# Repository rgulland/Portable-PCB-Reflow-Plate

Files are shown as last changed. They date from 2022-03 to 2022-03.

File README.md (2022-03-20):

# Portable PCB Reflow Plate
A PCB reflow plate optimized for medium size boards.  
Design, assembly & testing documentation at https://rgulland.com/blog/2022/3/11/reflow-heater

# Build Notes
Please don't build this unless you're confident working with mains power and have sufficient materials to do it safely. This build is rather fiddly and time consuming: if you're unsure I'm considering making a v2 that comes as a kit with custom electronics, contact me if you're interested in that.  
On initial power on, make sure to set a default power limit of 125-150W & 30.1V on the DSP5005 when using the AC input. Above these limits, the AC-DC converter components will have a shorter life due to high temperatures.

# LICENSE
This project is under the GPL v3 license. There's little to no IP here, as most components are COTS, so this is more an endorsement of keeping more things open source. Open source hardware projects are rare, so if yours is, thanks :)  
https://www.gnu.org/licenses/gpl-3.0.en.html

# Changes Since Blog
- Adjusted microcontroller port cutout
- Added draft to bottom cap to better tolerate 3D printed parts' first layer flange / 'elephant's foot'
- Separated code into multiple files & commented for readability

# Todo
- Improve code
  - Generally remove jank / simplify screen update system
  - Re-implement PID control
  - Add thermal runaway detection / better AC lockout
  - PID settings / tuning menu
  - Add curve edit mode
- Design / Build / Test v2 
  - SD card / spi flash / other permanent storage for reflow curves
  - Cheaper thermal insulation solution
  - Lower cost MCU (ideally w/ BLE or wifi for future expandability)
  - Wiring condensed into 3 custom PCBs to reduce assembly time
  - Smaller AC port (fused IEC 60320) & SPST switch
  - Larger cooling fan
  - Solution for cooling PCBs faster
  - SSR for finer PID control

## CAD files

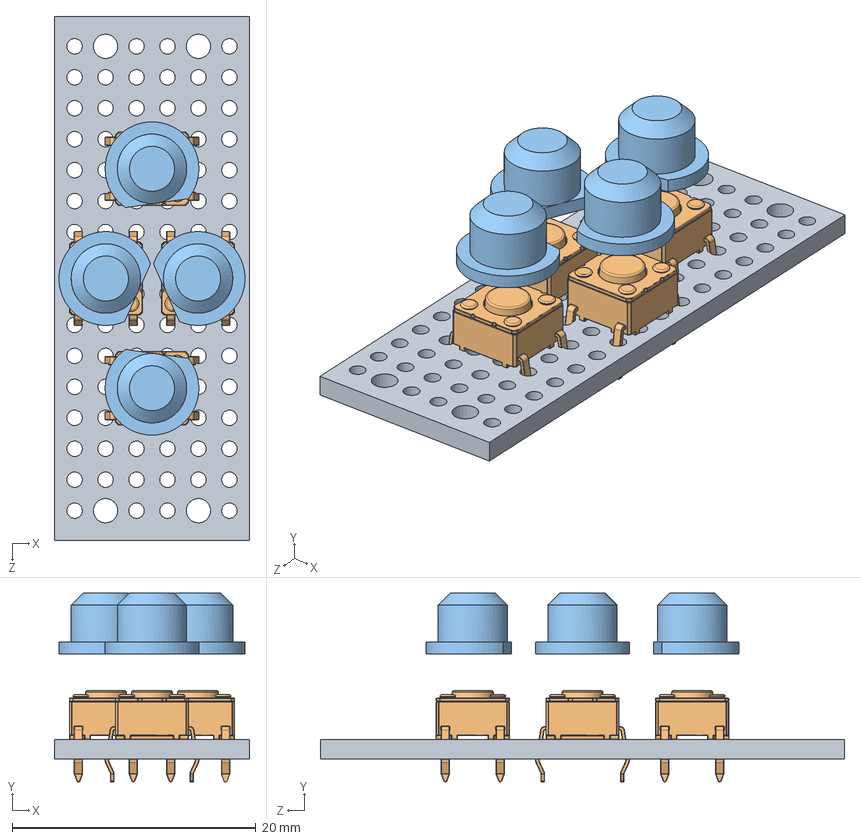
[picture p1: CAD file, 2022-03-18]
CAD/Button Assembly.SLDASM
16.0 x 15.5 x 43.0 mm
PCB Backplane
Push Tactile Button SPST-NO 6x6mm L=5mm Omron B3F-1020 x 4
Button Face x 4

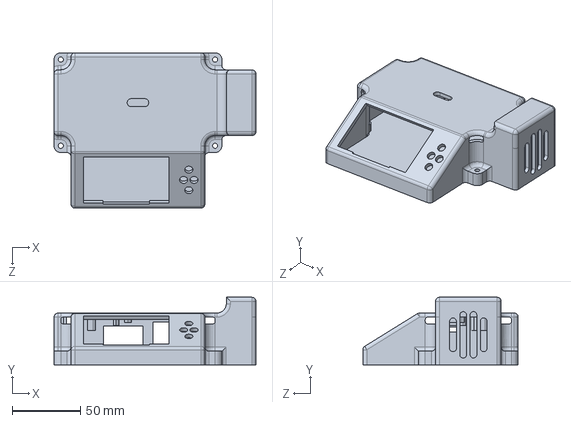
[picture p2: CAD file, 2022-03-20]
CAD/Shell.SLDPRT
148.2 x 49.6 x 114.1 mm

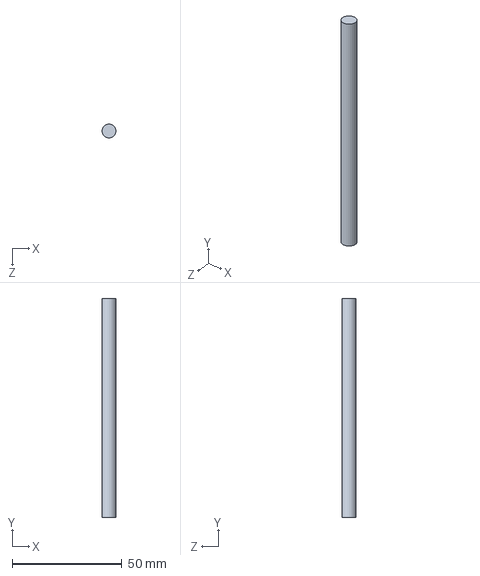
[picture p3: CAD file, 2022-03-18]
CAD/Simulation/Test.SLDPRT
6.35 x 100.0 x 6.35 mm

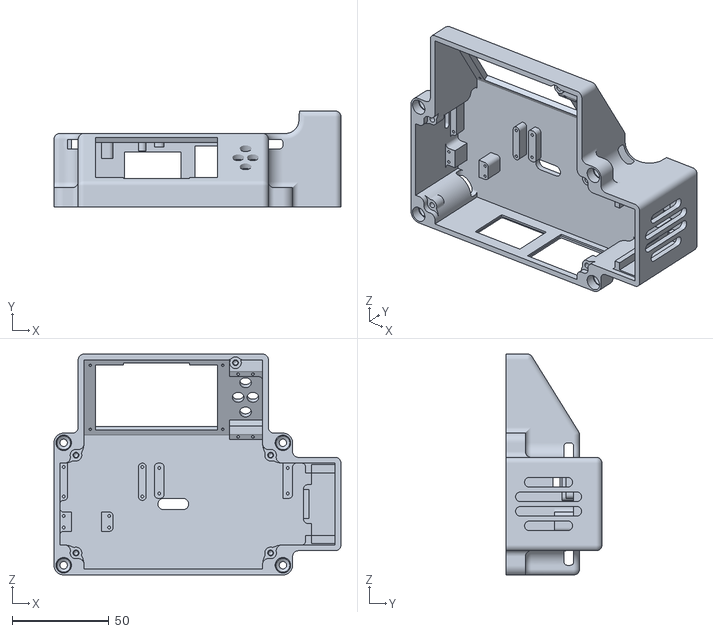
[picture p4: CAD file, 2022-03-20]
export/220224 shell v2/Shell.STL
148.2 x 49.6 x 114.1

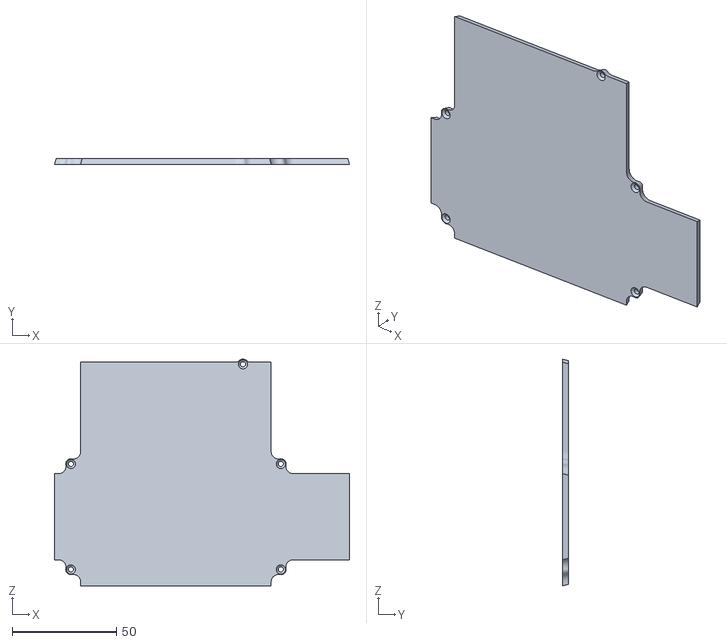
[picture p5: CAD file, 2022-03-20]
export/220224 shell v2/Bottom.STL
141.3 x 2.80 x 108.6

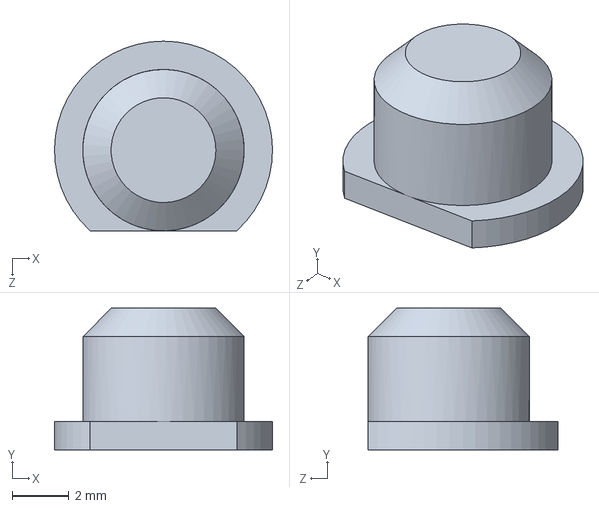
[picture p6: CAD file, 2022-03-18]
CAD/Button Face.SLDPRT
7.70 x 5.00 x 6.70 mm

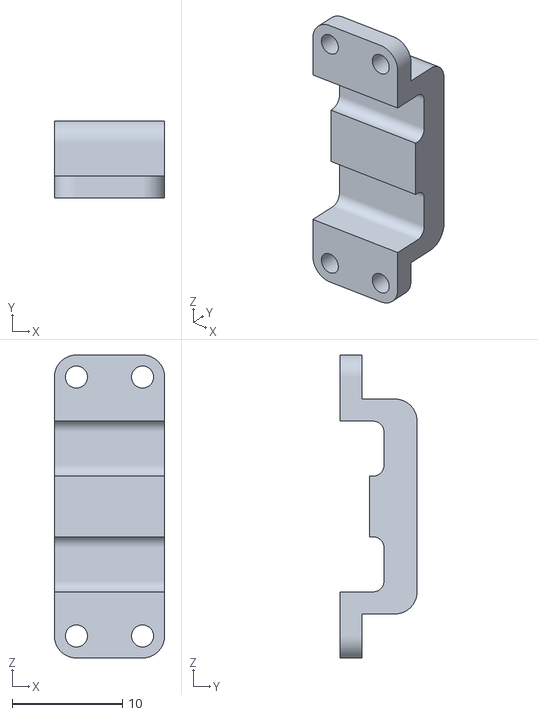
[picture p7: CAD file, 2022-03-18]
export/220224 shell v2/5V holderSLDPRT.STL
10.0 x 7.00 x 27.5

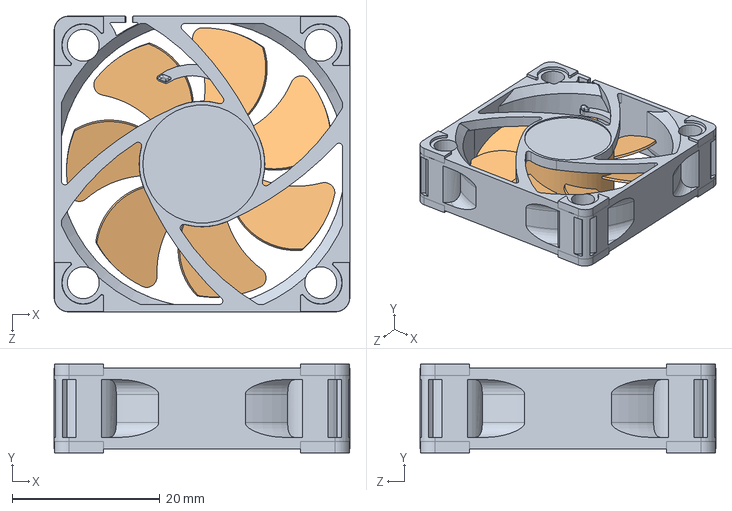
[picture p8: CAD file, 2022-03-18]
CAD/COTS/NF-A4x10 Fan.SLDASM
40.1 x 12.0 x 40.1 mm
Noctua-NF-A4x10 v1.step
Noctua nf-a8-pwm fan 80x80x25 v2.step

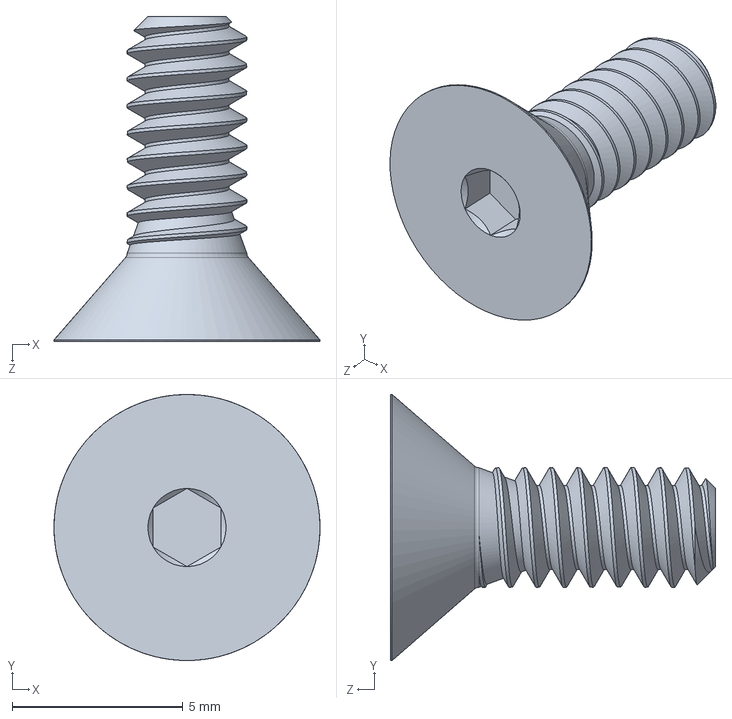
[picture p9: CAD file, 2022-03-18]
CAD/COTS/92210A146_18-8 Stainless Steel Hex Drive Flat Head Screw.SLDPRT
7.80 x 7.80 x 9.53 mm

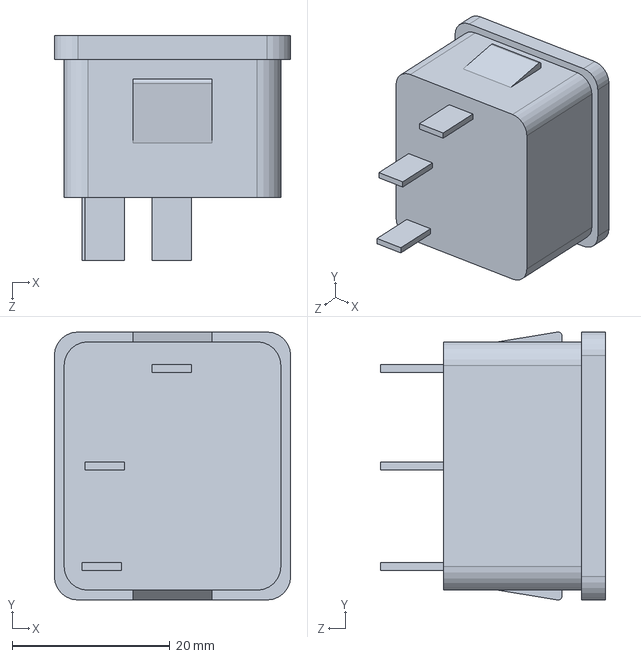
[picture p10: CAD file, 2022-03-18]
CAD/COTS/6200.4125.SLDPRT
30.0 x 34.0 x 28.5 mm

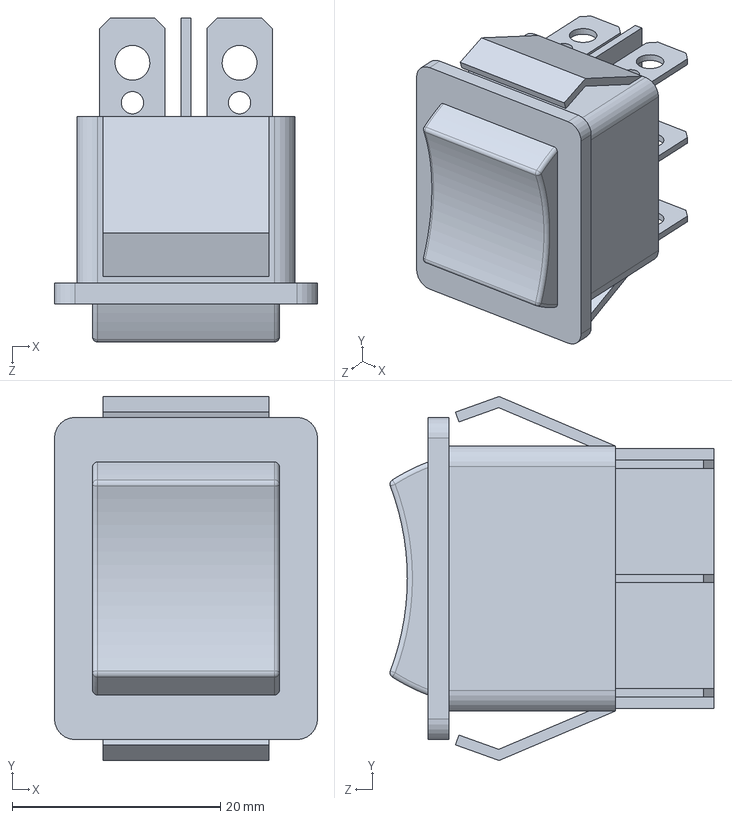
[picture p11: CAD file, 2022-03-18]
CAD/COTS/KCD2-203N.SLDPRT
25.3 x 35.0 x 31.2 mm

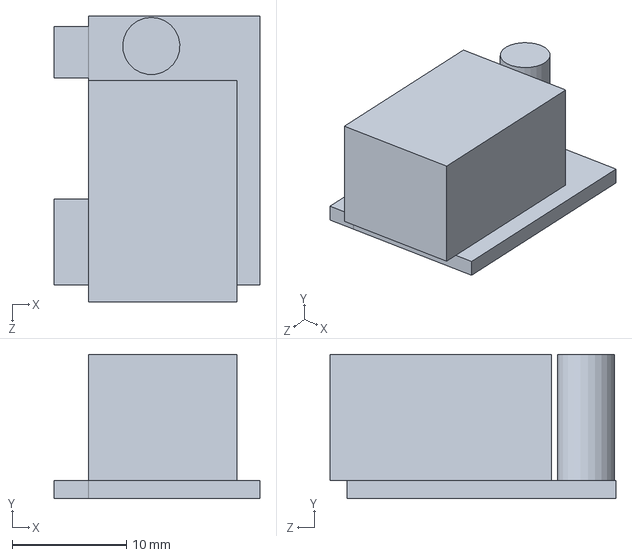
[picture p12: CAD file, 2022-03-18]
CAD/COTS/5V regulator.SLDPRT
18.0 x 12.6 x 25.0 mm

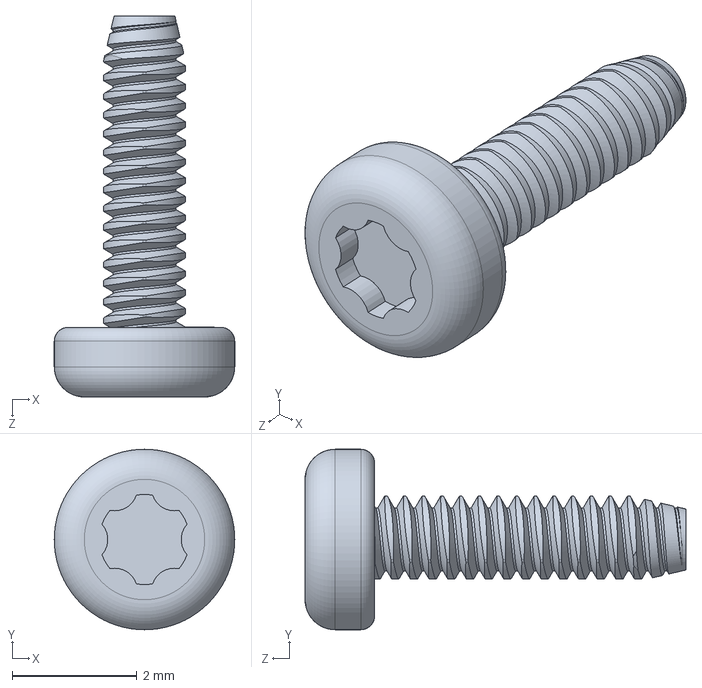
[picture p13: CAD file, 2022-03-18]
CAD/COTS/94209A113_Thread-Forming Screws for Soft Metal.SLDPRT
2.90 x 2.90 x 6.12 mm

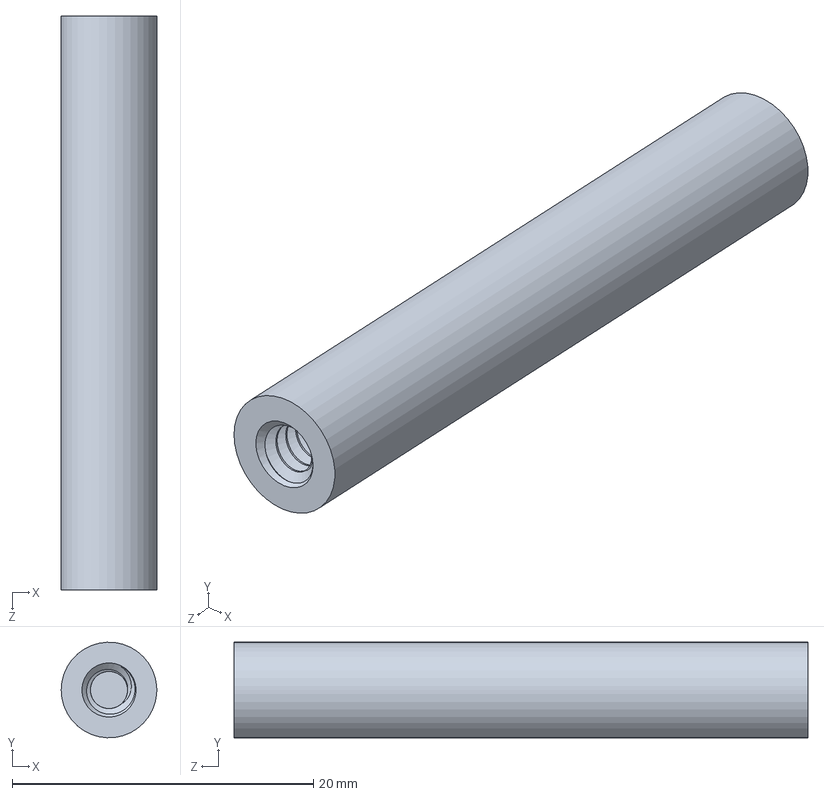
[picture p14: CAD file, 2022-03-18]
CAD/COTS/94335A121_Electrical-Insulating Female Threaded Standoff.SLDPRT
6.35 x 6.34 x 38.1 mm

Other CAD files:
CAD/5V holderSLDPRT.SLDPRT
export/220224 shell v2/Button Face.STL
CAD/COTS/PTC Resistive Heater.SLDPRT
CAD/COTS/PCB Backplane.SLDPRT
CAD/COTS/1H Relay board.SLDPRT
CAD/COTS/IEC 320 C13 Cable End.SLDPRT
CAD/COTS/OLED.SLDPRT
CAD/COTS/Push Tactile Button SPST-NO 6x6mm L=5mm Omron B3F-1020.SLDPRT

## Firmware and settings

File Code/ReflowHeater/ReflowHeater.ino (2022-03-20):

//#include ReflowHeater.h
/////////////////  library imports  //////////////////////////
#include "InterpolationLib.h"
#include <Adafruit_MAX31856.h>
#include <SPI.h>
#include <Wire.h>
#include <Adafruit_GFX.h>
#include <Adafruit_SSD1306.h>
#include <StateMachine.h>



/////////////////  Thermocouple library  //////////////////
#define DRDY_PIN 6
#define THERM_CS 7
Adafruit_MAX31856 maxthermo = Adafruit_MAX31856(THERM_CS);
bool newTemp=false;

/////////////////  OLED library  //////////////////
#define SCREEN_WIDTH 128 // OLED display width, in pixels
#define SCREEN_HEIGHT 64 // OLED display height, in pixels..
#define OLED_RESET     10 // Reset pin # (or -1 if sharing Arduino reset pin)
#define OLED_DC     9
#define OLED_CS     8
#define SCREEN_ADDRESS 0x3D ///< See datasheet for Address; 0x3D for 128x64, 0x3C for 128x32
Adafruit_SSD1306 display(SCREEN_WIDTH, SCREEN_HEIGHT, &SPI, OLED_DC, OLED_RESET, OLED_CS);

//////////////////  Interpolation & curve values  ////////////////
const int numValues = 6; 
const int maxCurves = 5;
double curveSeconds[maxCurves][numValues] = {{0,30,120,150,210,270},{0,90,180,210,240,300},{0,90,180,210,240,300},{0,90,180,210,240,300},{0,30,60,90,120,150}}; //preloaded reflow curve "x" values
double curveCelsius[maxCurves][numValues] = {{25,100,150,183,235,25},{25,90,130,138,165,25},{25,150,175,217,249,25},{25,75,90,100,125,25},{25,50,60,65,75,25}}; //preloaded reflow curve "y" values
const char* curveNames[maxCurves] = {"smd291ax","smdltlfp","smd291snl","user a","user b"}; 
int curveSelection = 0; //current selection index
const int graphYBot=59; //location & size of graph during reflow state
const int graphYTop=20;
const int graphXRight=123;
const int graphXLeft=5;
// const int histSpace=5;
// const int histDiam=5;
const int histSize=graphXRight-graphXLeft; //array for storing the acheived reflow values
int history[histSize]; 
int histIndex=0;  



const int blinkMillis=500;

////////////////  button press registration  //////////////
#define rightPin 2 //arduino pins for UI buttons
#define leftPin 3
#define upPin 4
#define downPin 18
long pressDuration=25; //millis durations for different button presses
long holdingDuration=500;
long heldDuration=holdingDuration;
long lastButtonMillis = 0; //time last button press started
long currentHoldMillis =0; //length of current button press

bool lastDown=false; //if down was pressed in last cycle   // down button debouncing and output bools
bool down=false; //if down is currently pressed
bool downHolding=false; //if long down is currently held
bool downPressed=false; //if short down press was released this cycle

bool lastUp=false; //up button 
bool up=false;
bool upHolding=false;
bool upPressed=false;

bool lastRight=false; //right button 
bool right=false;
bool rightHeld=false; //if long right press was just released
bool rightPressed=false;

bool lastLeft=false; //left button
bool left=false;
bool leftHeld=false;
bool leftPressed=false;

///////////////////  heater vars  /////////////////
bool heaterEnable = false;  // safety var for heater enabling / disabling
#define relay 20    //relay pin
float PID_kp=.015;  //proportional gain
// float PID_s=0;
// #define PID_ki=1;
// #define imax=.1;
//long last_millis =0; //vars for debuggging duration between temp readings
//long lastTemp=0;
float tempSet=0; //desired temp
float dc=0; //duty cycle for relay
float temp=0; //current temperature
int dc_duration=1000;

//////////////// state machine /////////////////////////////////
String state="Menu"; //text for current state, used in drawing status bar and updated on switching states, does not control state machine
StateMachine machine = StateMachine(); //initializes state machine

State* smenu = machine.addState(&menu);  //sets up functions used for main loop of each state in state machine
State* spreheat = machine.addState(&preheat);
State* sselect = machine.addState(&select);
//State* sedit = machine.addState(&edit);
State* sreflow = machine.addState(&reflow);

//////////////// menu state /////////////////////
int selection = 1;

//////////////// heater state /////////////////////
int preheatSet = 80; //default preheat setpoint, purposefully safe-ish temp

//////////////// edit curve state /////////////////////

//////////////// reflow state /////////////////////
long startMillis =0;

////////////////////////////Setup////////////////////////////Setup////////////////////////////Setup////////////////////////////Setup////////////////////////////
void setup() {
  // serial output //////
  Serial.begin(115200);
  while (!Serial) delay(10);

  // pin setup //////////
  pinMode(relay, OUTPUT);
  pinMode(DRDY_PIN, INPUT);
  pinMode(rightPin,INPUT_PULLUP);
  pinMode(leftPin,INPUT_PULLUP);
  pinMode(upPin,INPUT_PULLUP);
  pinMode(downPin,INPUT_PULLUP);

  // thermocouple setup //
  Serial.println("MAX31856 thermocouple test"); //this is all default code from example file
  if (!maxthermo.begin()) {
    Serial.println("Could not initialize thermocouple.");
    while (1) delay(10);
  }
  maxthermo.setThermocoupleType(MAX31856_TCTYPE_K);
  Serial.print("Thermocouple type: ");
  switch (maxthermo.getThermocoupleType() ) {
    case MAX31856_TCTYPE_B: Serial.println("B Type"); break;
    case MAX31856_TCTYPE_E: Serial.println("E Type"); break;
    case MAX31856_TCTYPE_J: Serial.println("J Type"); break;
    case MAX31856_TCTYPE_K: Serial.println("K Type"); break;
    case MAX31856_TCTYPE_N: Serial.println("N Type"); break;
    case MAX31856_TCTYPE_R: Serial.println("R Type"); break;
    case MAX31856_TCTYPE_S: Serial.println("S Type"); break;
    case MAX31856_TCTYPE_T: Serial.println("T Type"); break;
    case MAX31856_VMODE_G8: Serial.println("Voltage x8 Gain mode"); break;
    case MAX31856_VMODE_G32: Serial.println("Voltage x8 Gain mode"); break;
    default: Serial.println("Unknown"); break;
  }
  maxthermo.setConversionMode(MAX31856_CONTINUOUS);

  // screen setup //
  if(!display.begin(SSD1306_SWITCHCAPVCC, SCREEN_ADDRESS)) {// set up screen SSD1306_SWITCHCAPVCC = generate display voltage from 3.3V internally
    Serial.println(F("SSD1306 allocation failed"));
    for(;;); // Don't proceed, loop forever
  }
  smenu->addTransition(&transitionMenuPreheat,spreheat); //adds transitions to relevant states
  spreheat->addTransition(&transitionPreheatMenu,smenu);  
  smenu->addTransition(&transitionMenuSelect,sselect);  
  sselect->addTransition(&transitionSelectMenu,smenu);  
  sselect->addTransition(&transitionSelectReflow,sreflow);  
  //sselect->addTransition(&transitionSelectEdit,sedit);  
  //sedit->addTransition(&transitionEditSelect,sselect);  
  sreflow->addTransition(&transitionReflowSelect,sselect);  
}

////////////////////////////Main Loop////////////////////////////Main Loop////////////////////////////Main Loop////////////////////////////Main Loop////////////////////////////
void loop() {
  updateButtons(); 
  readThermocouple();
  machine.run(); // checks for state machine transitions and then runs the function correlating to the current state 
  display.display();  
  drive(PID()); //drives heater module based on set temp and current temp
}


////////////////////////////Outputs////////////////////////////Outputs////////////////////////////Outputs////////////////////////////Outputs////////////////////////////
float PID(){//defines duty cycle based on set temp and current temp, currently only P, should add in integral term to eliminate steady state error
  // Serial.print(tempSet-temp);
  // Serial.print(", ");
  // Serial.println((.1*log(tempSet-temp+1)));

  if(temp>=tempSet){//in case function is behaving poorly, still cools if above value
    return 0;
  }
  return max((.1*log(tempSet-temp+1)),0);//logarythmic is better than linear (since high duty cycles are really bad) and PID was being finicky
  //.1=
}
void drive(float dc){//drives relay based on duty cycle
  if(((millis()%dc_duration) < (dc*dc_duration))&&heaterEnable){ //implements duty cycle and checks heaterEnable
    digitalWrite(relay, HIGH);   //enables heater
  }else{
    digitalWrite(relay, LOW);  //disables heater
  }
}

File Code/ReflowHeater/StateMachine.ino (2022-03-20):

////////////////////////////States////////////////////////////States////////////////////////////States////////////////////////////States////////////////////////////
/*
This 

*/

//////////////////////////// Menu //////////////////////////// Menu ////////////////////////////
void menu(){ //simple menu for moving to selection or preheat states
  if(machine.executeOnce){ //executes on first cycle in menu
    state="Menu";
    display.clearDisplay();
    drawStatusBar(); //only draws full status bar first time in loop
    heaterEnable = false;//turns heater off
    tempSet=0;
  }else if(newTemp){ //updates status bar if there's a new temp
    updateStatusBarTemp();    
  }              
  drawBlink(" Preheat      ",20,25,(selection==1));
  drawBlink(" Select Reflow",20,40,(selection==2));

  if((selection==1)&&downPressed){     //change menu selection w/ up and down
    selection++;
  }else if (upPressed){
    selection--;
  }
}
bool transitionMenuPreheat(){ //holding right -> preheat state
  //Serial.print("SITT preheat?? ");  //Serial.println(((selection==1)&&rightHeld));
  return(((selection==1)&&rightHeld));  
}
bool transitionMenuSelect(){ //holding right -> select state
  return(((selection==2)&&rightHeld));  
}

//////////////////////////// Select //////////////////////////// Select ////////////////////////////
void select(){  //displays loaded reflow curves and allows selection among them
  if(machine.executeOnce){//executes on first cycle in select state
    state="Select";
    heaterEnable=false;
    tempSet=0;    
    display.clearDisplay();
    drawStatusBar(); 
    drawSelection(); //draws details (temp, time, curve) for the current selection
  }else if(newTemp){
    updateStatusBarTemp();
  }
  if(downPressed&&(curveSelection<maxCurves-1)){ //moves to different selection based on button presses
    curveSelection++;
    drawSelection();    
  }else if(upPressed&&(curveSelection>0)){
    curveSelection--;
    drawSelection();
  }
  for(int i=0; i<maxCurves; i++){ //draws all curves in list on screen, current selection blinking
    drawBlink(curveNames[i],2,(10*i+15),(i==curveSelection)); 
  }
}
bool transitionSelectMenu(){ //holding left -> menu state
  return(leftHeld);  
}
bool transitionSelectReflow(){ //holding right -> reflow state
  return(rightHeld);
}

//////////////////////////// Reflow //////////////////////////// Reflow ////////////////////////////
void reflow(){ //executes the selected reflow curve when user holds right
  if(machine.executeOnce){ //draws selected reflow graph and title 
    state="Reflow";
    for(int i=0; i<histSize; i++){
      history[i]=0;
    }    display.clearDisplay();
    drawStatusBar();    
    drawGraph(graphXLeft, graphXRight, graphYBot, graphYTop);
    display.setTextSize(1);  
    display.setTextColor(SSD1306_WHITE, SSD1306_BLACK);
    display.setCursor(8,13);
    display.print(F(curveNames[curveSelection]));
    display.print(F(": "));
    display.print(F(int(curveCelsius[curveSelection][numValues-2])));
    display.print(F("C  "));
  }else if(rightHeld){ //starts reflow curve
    heaterEnable=!heaterEnable;
    if(heaterEnable){ //redraws graph on starting reflow to eliminate old history values if there are any
      drawGraph(graphXLeft, graphXRight, graphYBot, graphYTop);
      startMillis=millis();
    }
  }else if(newTemp){
    updateStatusBarTemp();
  }
  if(heaterEnable){ //if currently reflowing
    tempSet=Interpolation::Linear(curveSeconds[curveSelection], curveCelsius[curveSelection], numValues, (millis()-startMillis)/1000, true);//sets temp based on curve and time
    //Serial.println(tempSet);
    if((millis()-startMillis)/1000>curveSeconds[curveSelection][numValues-1]){ //stops reflow once curve time reached
      heaterEnable=false;
    }
    histIndex=int((millis()-startMillis)/1000/curveSeconds[curveSelection][numValues-1]*histSize);//indexes into history based on elapsed time such that each even durations are captures by each pixel
    //Serial.print(histIndex);
    if(history[histIndex]==0){//if there's no history, records a value
      history[histIndex]=temp;
      //Serial.println("YAY");
      display.drawPixel(graphXLeft+histIndex,graphYBot-int(temp*(graphYBot-graphYTop)/(curveCelsius[curveSelection][numValues-2])),SSD1306_WHITE); //draws current temp on graph
    }
  }else{//if not currently reflowing, sets desired temp to 0
    tempSet=0;
  }


  //calculate & set temp required
  //drawGraph()
}
bool transitionReflowSelect(){ //holding left -> select state
  return(leftHeld);  

}

//////////////////////////// Preheat //////////////////////////// Preheat ////////////////////////////
void preheat(){ 
  //Serial.println("preheat");
  if(machine.executeOnce){
    state="Preheat";
    display.clearDisplay();
    drawStatusBar();    
    display.setTextSize(2);
    display.setCursor(20,30);
    display.setTextColor(SSD1306_WHITE, SSD1306_BLACK);
    drawSpacedRight(temp);  
    display.setCursor(56,30);
    display.print(F("/"));
    display.setCursor(68,30);
    drawSpacedRight(preheatSet);  

  }else if(newTemp){ //update temps if new temps available
    //updateStatusbar();
    display.setTextSize(2);
    display.setCursor(20,30);
    display.setTextColor(SSD1306_WHITE, SSD1306_BLACK);
    drawSpacedRight(temp);  
    updateStatusBarTemp();    
  }
  if (upPressed||upHolding){ //adjusts temperature
    preheatSet++;
    display.setTextSize(2);
    display.setCursor(68,30);
    display.setTextColor(SSD1306_WHITE, SSD1306_BLACK);
    drawSpacedRight(preheatSet);     
  }else if(downPressed||downHolding){
    preheatSet--;
    display.setTextSize(2);
    display.setCursor(68,30);
    display.setTextColor(SSD1306_WHITE, SSD1306_BLACK);
    drawSpacedRight(preheatSet);        
  }else if(rightHeld){
    heaterEnable=!heaterEnable; 
  }
  if(heaterEnable){ //enables heater
    tempSet=preheatSet;
  }else{
    tempSet=0;
  }
}
bool transitionPreheatMenu(){ //holding left -> menu state
  //Serial.print("should I transition to menu?? ");//Serial.println(leftHeld);
  return(leftHeld);
}


/*
void edit(){
  //left right -> change digit, up down -> increment digit
  //hold back exit -> right 

  if(leftHeld){
    //state="Select Curve";
  }else if(rightHeld&&!heaterEnable){
    //state="Reflow";
  }

  //display name, return setpoints 1 time 1, return setpoint 2 time 2, ...setpoint 5 time 5
  //
}
*/

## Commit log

2022-03-18 Added all source and export files as tested and assembled.
    This reflects the work documented at https://rgulland.com/blog/2022/3/11/reflow-heater
    [1H Relay board.SLDPRT, 5V holderSLDPRT.SLDPRT, 5V holderSLDPRT.STL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]
2022-03-20 Small CAD tweaks, code readability improvements
    - Adjusted microcontroller port cutout upwards ~1 mm
    - Added 15 degree draft to bottom cap to better tolerate 3D printed parts' first layer flange / 'elephant's foot'
    - Separated code into multiple .ino files
    - Commented functions for readability
    [Bottom.STL, Shell.SLDPRT, Shell.STL]
